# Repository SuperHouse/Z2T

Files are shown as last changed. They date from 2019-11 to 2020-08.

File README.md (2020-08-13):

Zigbee2Tasmota Zigbee Coordinator
=================================

Combines a Wemos D1 Mini and a Z-0001 module with CC2531 CC.

Uses the Zigbee2Tasmota firmware to operate as a Zigbee Coordinator.

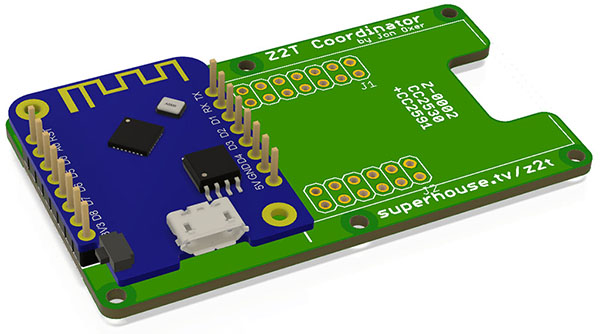
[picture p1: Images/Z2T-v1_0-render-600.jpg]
PCB render


Features:

 * ESP8266 to run Zigbee2Tasmota
 * CC2531 Zigbee interface
 * 3D-printable case

More information is available at:

  https://www.superhouse.tv/z2t

Hardware
--------
The "Hardware" directory contains the PCB design as an EAGLE project.
EAGLE PCB design software is available from Autodesk free for
non-commercial use.

Firmware
--------
The "Firmware" directory contains example firmware as an Arduino
project.

Enclosure
---------
The "Enclosure" directory contains STLs for a case that can be
3D-printed.

The two halves of the case should be printed with the flat face down to
the printer bed.

The case can be held shut by 8mm M3 bolts.

Credits
-------
 * Jonathan Oxer <jon@oxer.com.au>

License
-------
Copyright 2020 SuperHouse Automation Pty Ltd  www.superhouse.tv  

The hardware portion of this project is licensed under the TAPR Open
Hardware License (www.tapr.org/OHL). The "license" folder within this
repository contains a copy of this license in plain text format.

The software portion of this project is licensed under the Simplified
BSD License. The "licence" folder within this project contains a
copy of this license in plain text format.

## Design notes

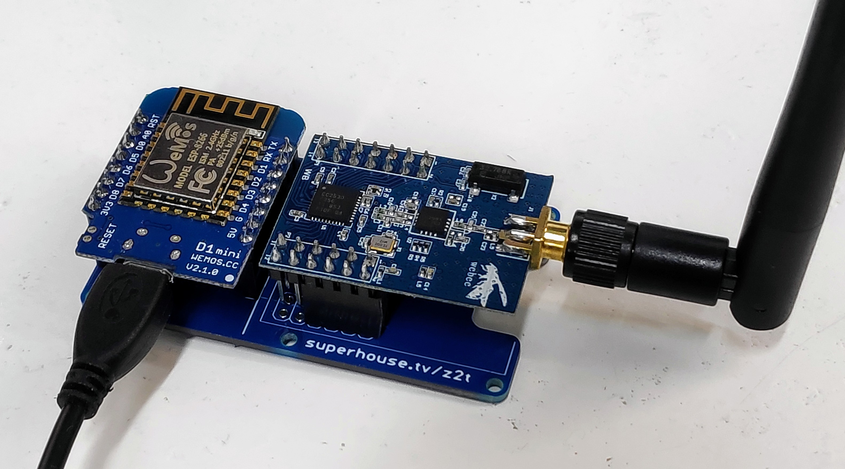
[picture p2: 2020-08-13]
Images/2019-11-21 10.12.14.jpg

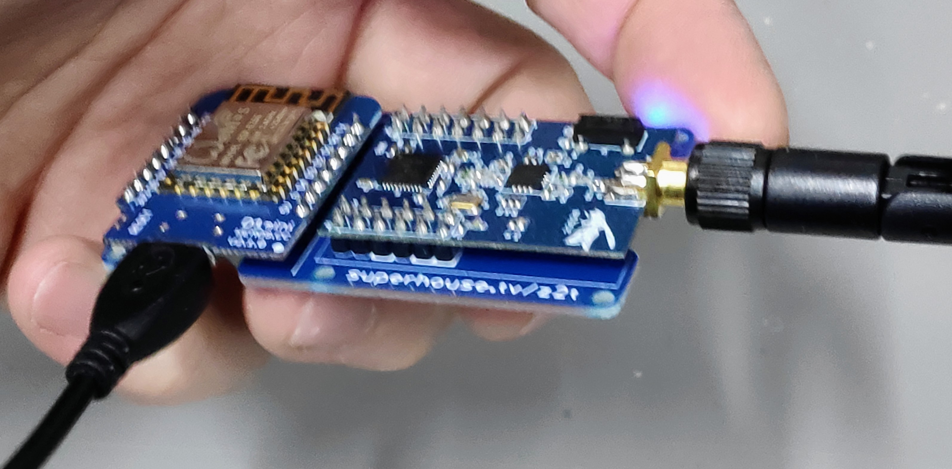
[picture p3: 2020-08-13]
Images/2019-12-08 09.25.52.jpg

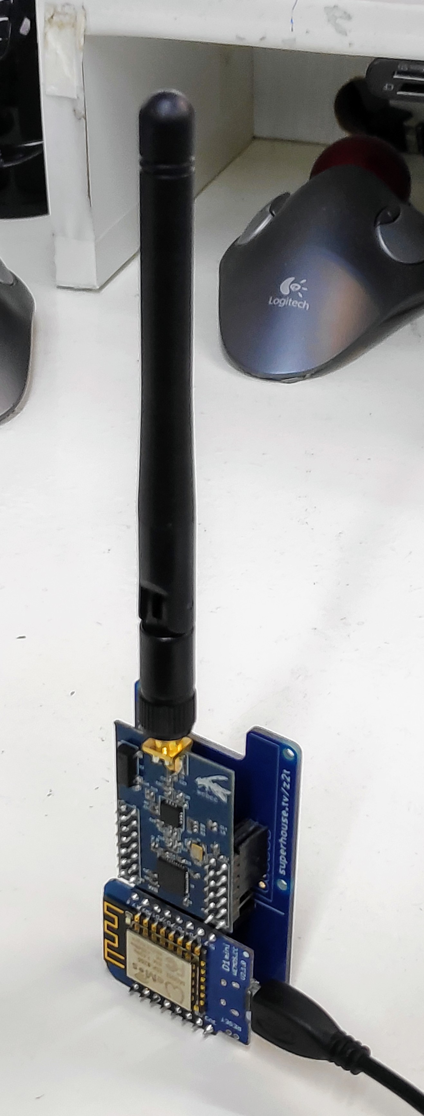
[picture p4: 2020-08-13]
Images/2019-11-21 10.18.53.jpg

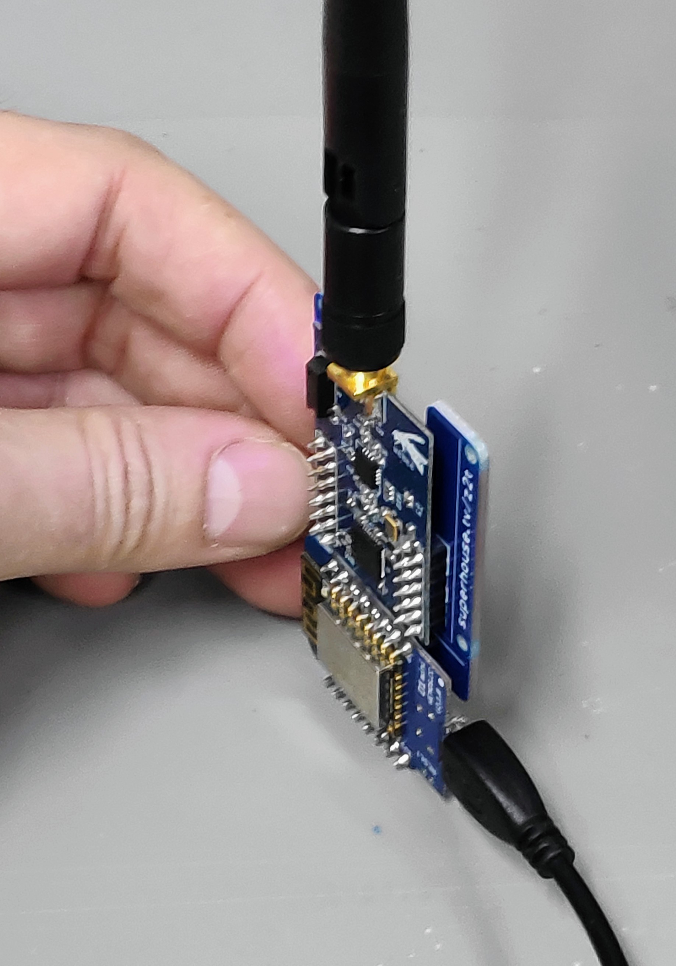
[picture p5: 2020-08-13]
Images/2019-12-08 09.25.38.jpg

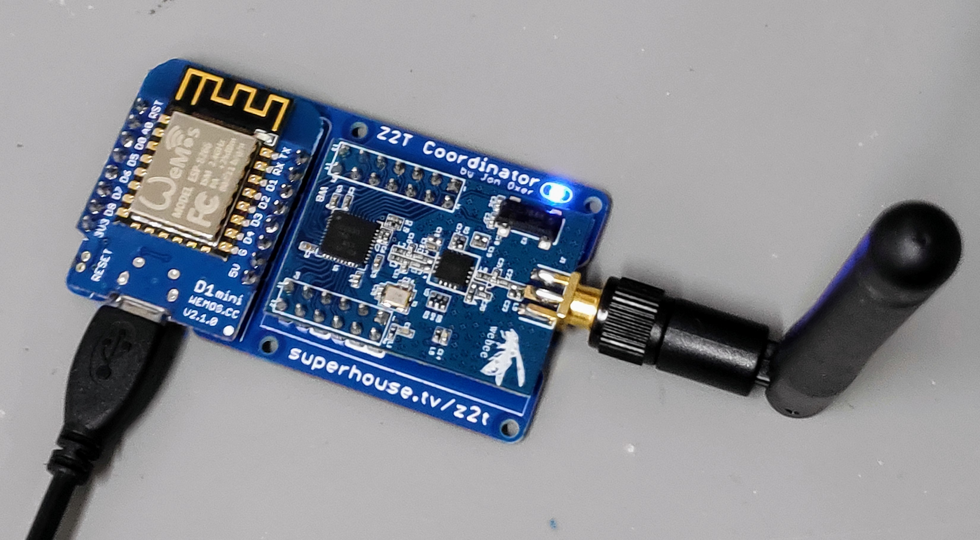
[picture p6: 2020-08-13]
Images/2019-12-08 09.25.14.jpg

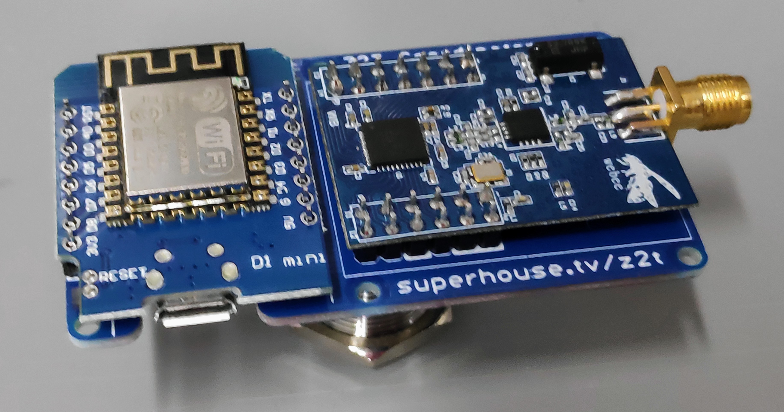
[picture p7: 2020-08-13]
Images/2019-12-06 10.09.29.jpg

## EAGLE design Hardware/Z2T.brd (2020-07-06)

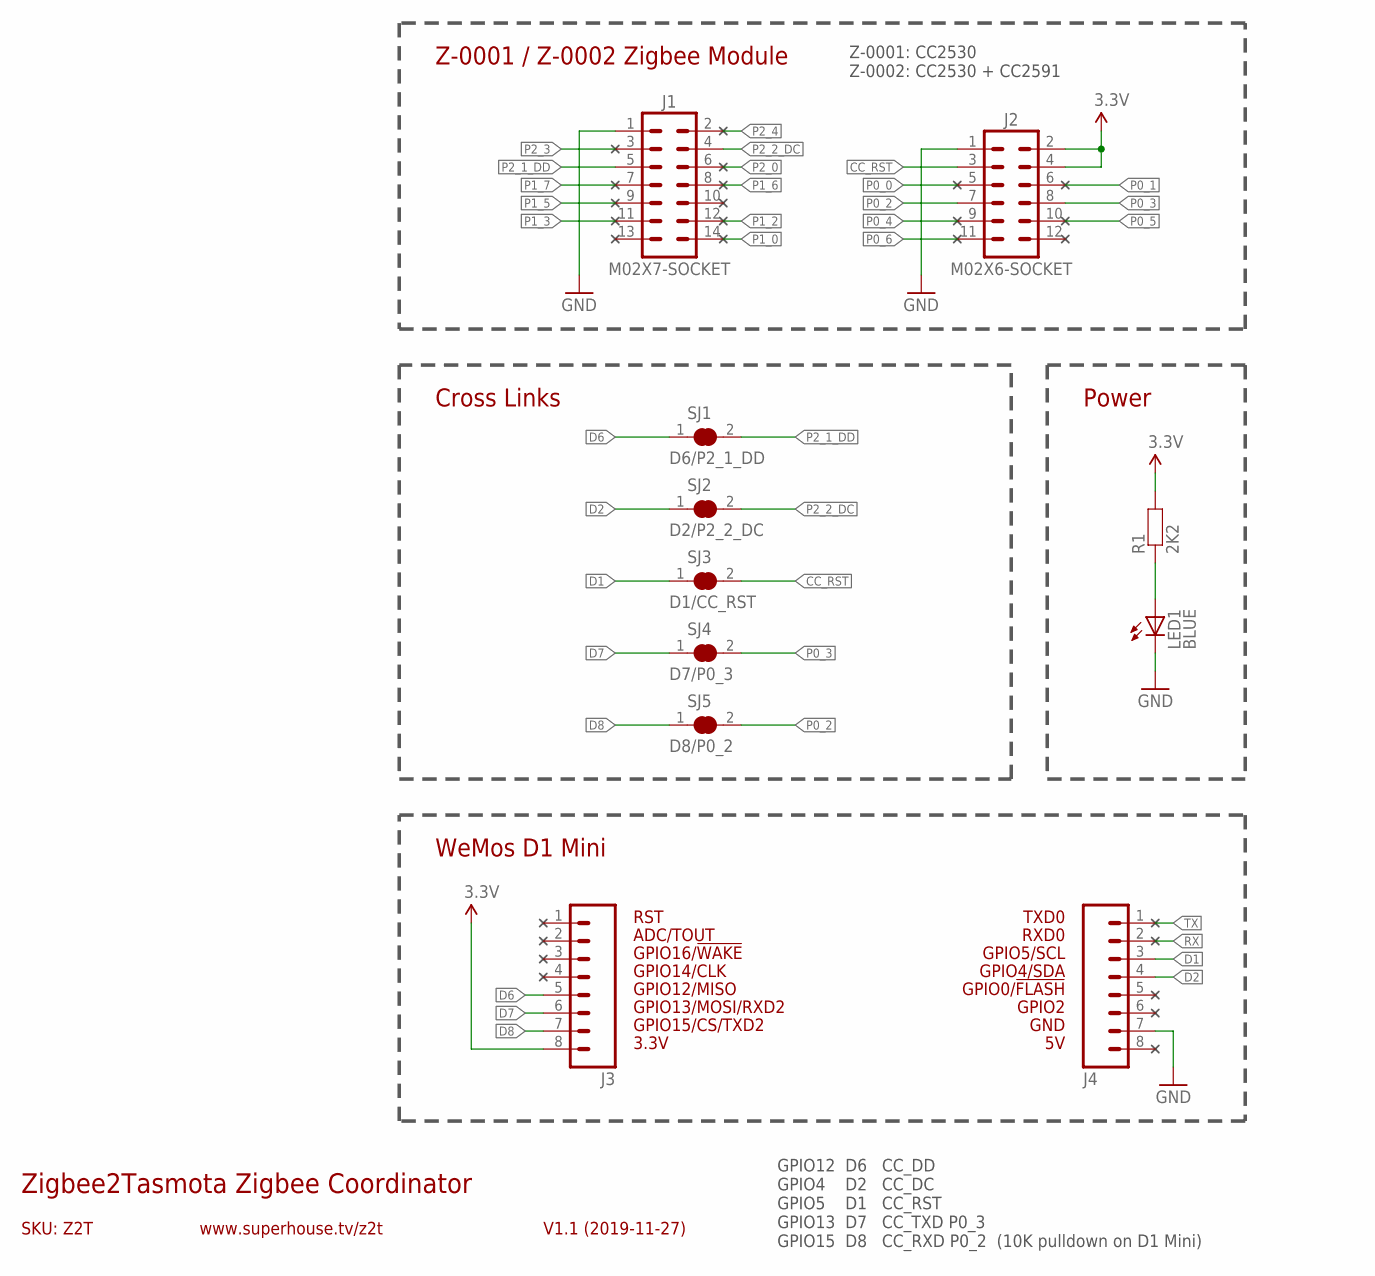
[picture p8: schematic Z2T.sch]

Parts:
J1: M02X7-SOCKET; 2X07-S
J2: M02X6-SOCKET; 2X06-S
J3, J4: M08; 1X08
LED1: BLUE; LED-0603
R1: 2K2; R0603
SJ1: D6/P2_1_DD; SJC
SJ2: D2/P2_2_DC; SJC
SJ3: D1/CC_RST; SJC
SJ4: D7/P0_3; SJC
SJ5: D8/P0_2; SJC

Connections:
3.3V: J2.2, J2.4, J3.8, R1.2
CC_RST: J2.3, SJ3.2
D1: J4.3, SJ3.1
D2: J4.4, SJ2.1
D6: J3.5, SJ1.1
D7: J3.6, SJ4.1
D8: J3.7, SJ5.1
GND: J1.1, J2.1, J4.7, LED1.C
unnamed: LED1.A, R1.1
P0_0: J2.5
P0_1: J2.6
P0_2: J2.7, SJ5.2
P0_3: J2.8, SJ4.2
P0_4: J2.9
P0_5: J2.10
P0_6: J2.11
P1_0: J1.14
P1_2: J1.12
P1_3: J1.11
P1_5: J1.9
P1_6: J1.8
P1_7: J1.7
P2_0: J1.6
P2_1_DD: J1.5, SJ1.2
P2_2_DC: J1.4, SJ2.2
P2_3: J1.3
P2_4: J1.2
RX: J4.2
TX: J4.1

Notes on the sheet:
GPIO2
GPIO0/!FLASH
GPIO12/MISO
GPIO4/SDA
GPIO5/SCL
RXD0
TXD0
GPIO13/MOSI/RXD2
GPIO14/CLK
GPIO15/CS/TXD2
GPIO16/!WAKE
SKU: Z2T
Zigbee2Tasmota Zigbee Coordinator
V1.1 (2019-11-27)
www.superhouse.tv/z2t
ADC/TOUT
GPIO12 D6 CC_DD GPIO4 D2 CC_DC GPIO5 D1 CC_RST GPIO13 D7 CC_TXD P0_3 GPIO15 D8 CC_RXD P0_2 (10K pulldown on D1 Mini)
GND
3.3V
RST
Cross Links
Z-0001 / Z-0002 Zigbee Module
WeMos D1 Mini
Power
Z-0001: CC2530 Z-0002: CC2530 + CC2591

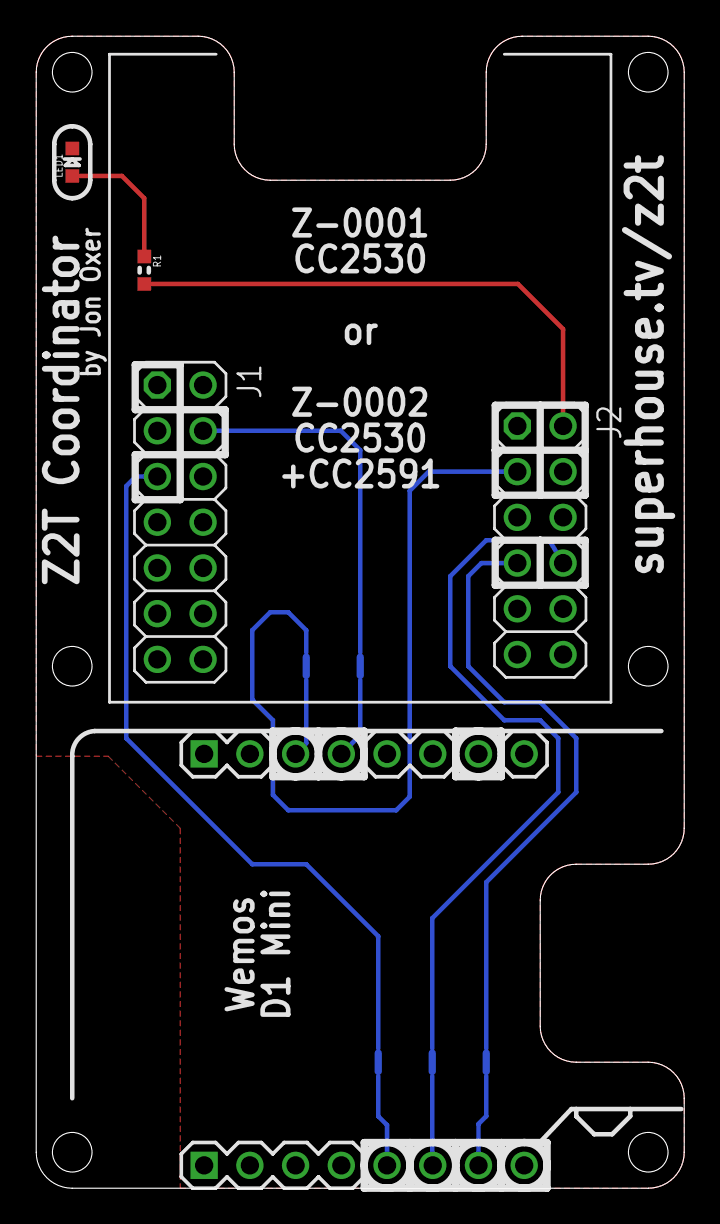
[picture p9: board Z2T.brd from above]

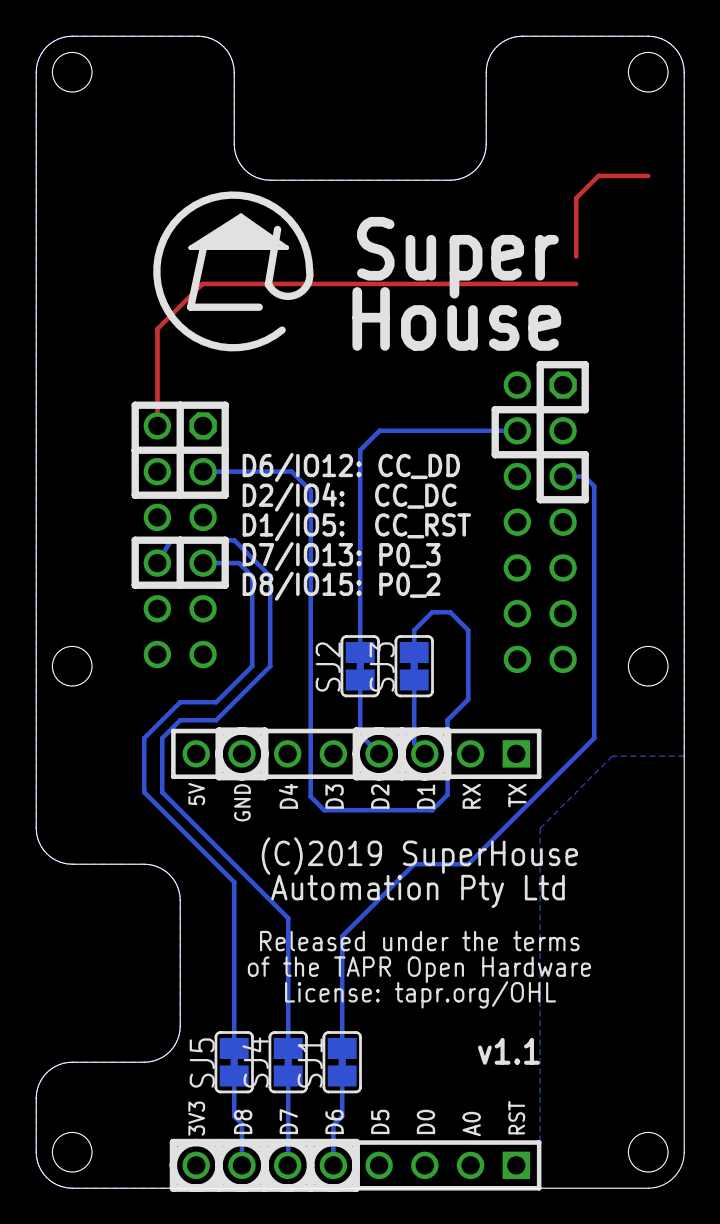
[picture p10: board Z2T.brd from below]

Board: 2 copper layers, 36.0 x 64.0 mm, 11 parts (5 on the bottom side), 13 nets.

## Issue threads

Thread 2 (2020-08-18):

Enclosure STL files

hallard, 2020-08-18:
Hi john,

I can't find the folder with the enclosure file as stated in the readme, did I missed something?

Also as #1 the link is broken.

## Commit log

2018-03-28 Import of project from 2017
    [D1MPIXEL.brd, D1MPIXEL.sch]
2019-11-09 Rough position on board
    [D1MPIXEL.brd, D1MPIXEL.sch, Z2T.brd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]
2019-11-10 Mechanical adjustments on Zigbee module
    [Z2T.brd, Z2T.sch]
2019-11-12 Final routing, silkscreen, DRC, and docs for v1.0 release
    [Z2T.brd, Z2T.sch]
2019-11-20 Fixed spacing on Zigbee module headers
    [Z2T.brd, Z2T.sch]
2019-11-26 Added power LED, clearance for USB socket, and pulled back copper near WiFi antenna
    [Z2T.brd, Z2T.sch]
2019-11-26 Schematic clarification, silkscreen tweaks
    [Z2T.brd, Z2T.sch]
2020-03-17 Final synch with Fusion 360 for v1.1 release
    [Z2T.brd]
2020-07-06 Replaced header footprint
    [Z2T.brd, Z2T.sch]
2020-08-13 More restructuring
    [Z2T.brd, Z2T.sch]

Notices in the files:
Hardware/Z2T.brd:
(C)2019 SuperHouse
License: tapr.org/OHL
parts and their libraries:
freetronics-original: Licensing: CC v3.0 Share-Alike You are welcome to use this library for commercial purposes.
